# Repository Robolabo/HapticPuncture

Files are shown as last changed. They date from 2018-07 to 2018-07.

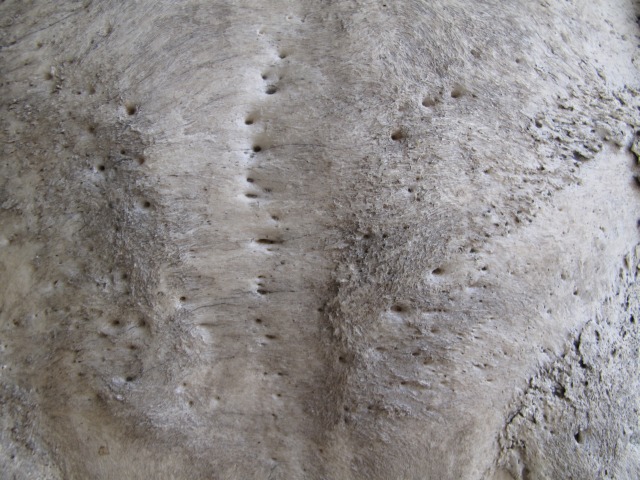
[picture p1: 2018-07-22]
resources/images/bone.jpg

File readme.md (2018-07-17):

HapticPuncture - The Open Source Haptic Puncture Simulator
----------------------------------------------------------

Introduction
============

HapticPuncture Simulator is an innovative simulation system for epidural anesthesia training. Among its many advantages it is important to say that it is virtual-reality (VR) based, which means that can be used indefinitely. Moreover, it is a low-cost, open-source, customizable prototype that opens doors to new procedure simulators in multiple specialties of medicine.

This guide allows to any user to install the simulator downloaded from \url{www.github.com/robolabo}, and to start using the proposed simulator in \textbf{Ubuntu 14.04}. Furthermore, instructions about how to create new applications are detailed. 

HapticPuncture Simulator is composed by two main modules: an haptic device and a virtual environment. In order to use this system, some requirements exist.

Online Resources
================

* The release is available online in GitHub. 

  https://github.com/Robolabo

* Instructions on how to get started can be found in the 
  documentation folder.

  doc/getting-started.pdf

Materials
=========

The materials used in for the HapticPuncture Simuator 
prototype are listed below. A more detailed list can 
be found in the documentation folder.

  doc/getting-started.pdf

* A computer with Ubuntu 14.04

* An Arduino Due board

* A motor's board X-NUCLEO-IHM04A1

* A voltage generator

* A DC motor MINIMOTOR 2842-012C

* An encoder HEDS 5540 A

* 3D printed structures

* Two Linear Shaft Rail Bars

* Two bearings

* A transmission tendon

* A capstan

* A pulley

Software Requirements
=====================

HapticPuncture requires the following software resources:

* CHAI3D platform.

* Arduino IDE, with two libraries installed: Encoder.h and DueTimer.h.

* The code provided in this folder.

Libraries needed for CHAI3D:
* GLUT package
$sudo apt-get install freeglut3 freeglut3-dev
$sudo apt-get install binutils-gold
* usb-1.0
$sudo apt-get install libusb-1.0-0-dev
* libasound2-dev
$sudo apt-get install libasound2-dev

* Additionally, we need a compiler (gcc):
$sudo apt-get install build-essentials
* pthread 
* rt 
* dl 
* GL 
* GLU 
* usb-1.0

Start the system
================

The C++ code to run the virtual environment needs to be compiled. Firstly, copy the 07-HapticPuncture directory from <HapticPunture directory>/Chai3D_code to <CHAI3d_directory>/GEL/modules/GEL/examples/GLFW/
Then, run in the command line:
$ cd <HapticPunture directory>/Chai3D_code/07-HapticPuncture
$ make

Next, to run HapticPuncture the following code scripts need to be run:
* `Arduino_code/HapticPuncture_arduino.ino` in arduino
* `Chai3D_code/07-HapticPuncture/obj/release/lin-x86_64-ccHapticPuncture/HapticPuncture` by typing in the terminal from lin-x86_64-ccHapticPuncture directory: $ ./HapticPuncture

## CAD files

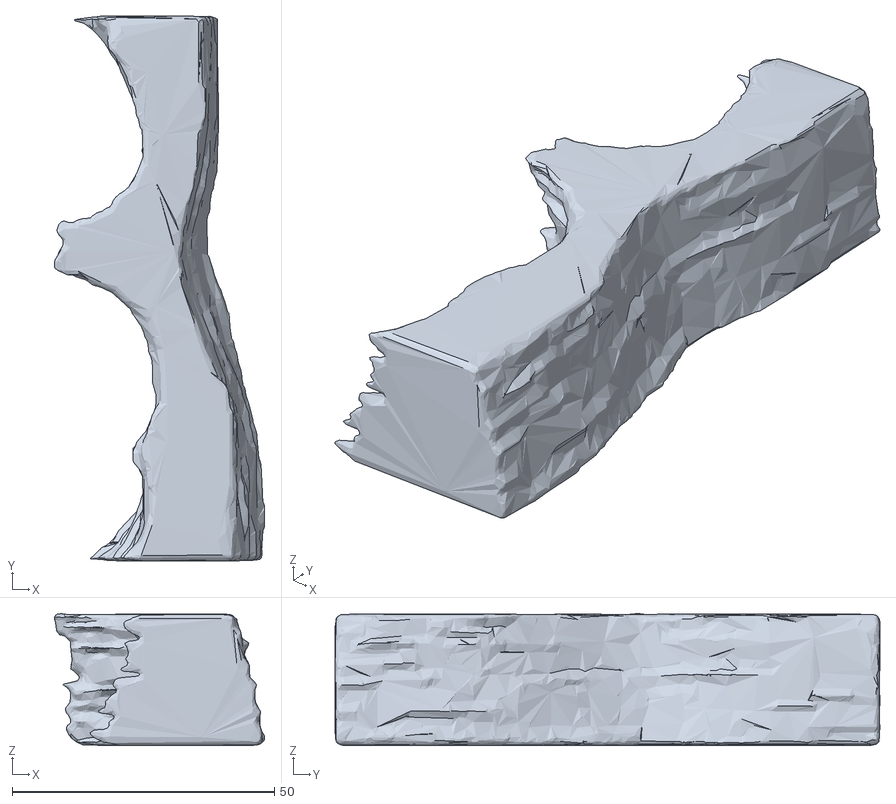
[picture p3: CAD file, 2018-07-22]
resources/models/conjunctive/conjunctive_filled_center.stl
40.1 x 104.0 x 25.2

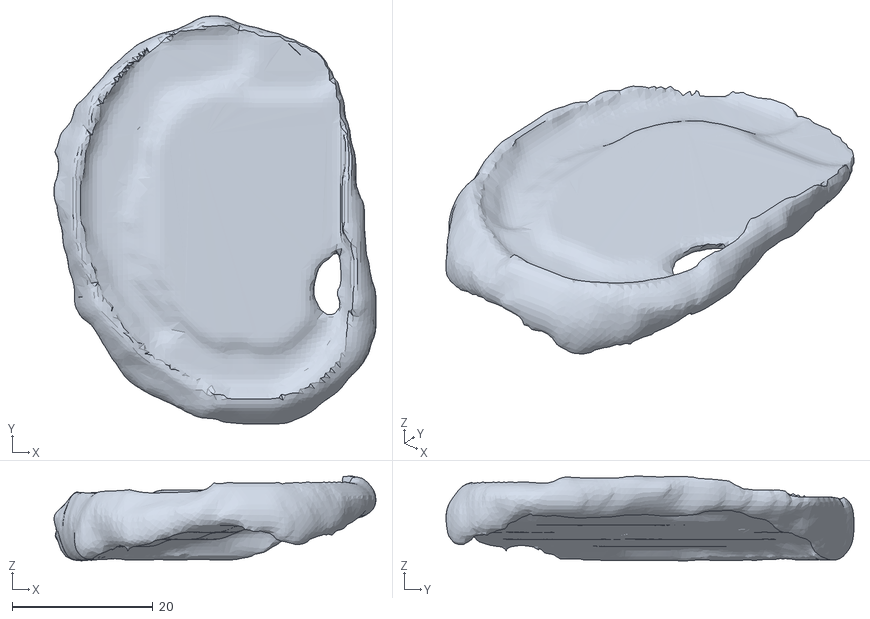
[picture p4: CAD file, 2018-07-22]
resources/models/disk/disk_filled_center.stl
45.7 x 57.9 x 12.0

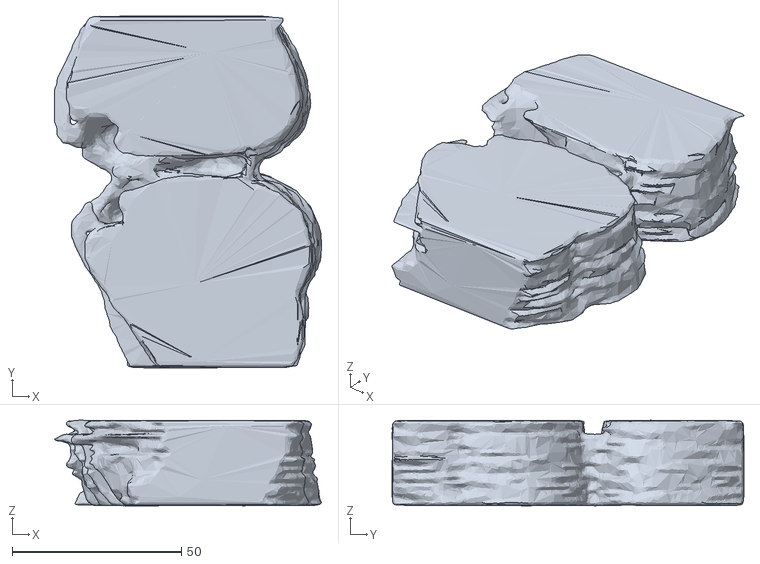
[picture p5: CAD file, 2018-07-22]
resources/models/muscle/muscle_filled_center.stl
79.0 x 104.0 x 25.4

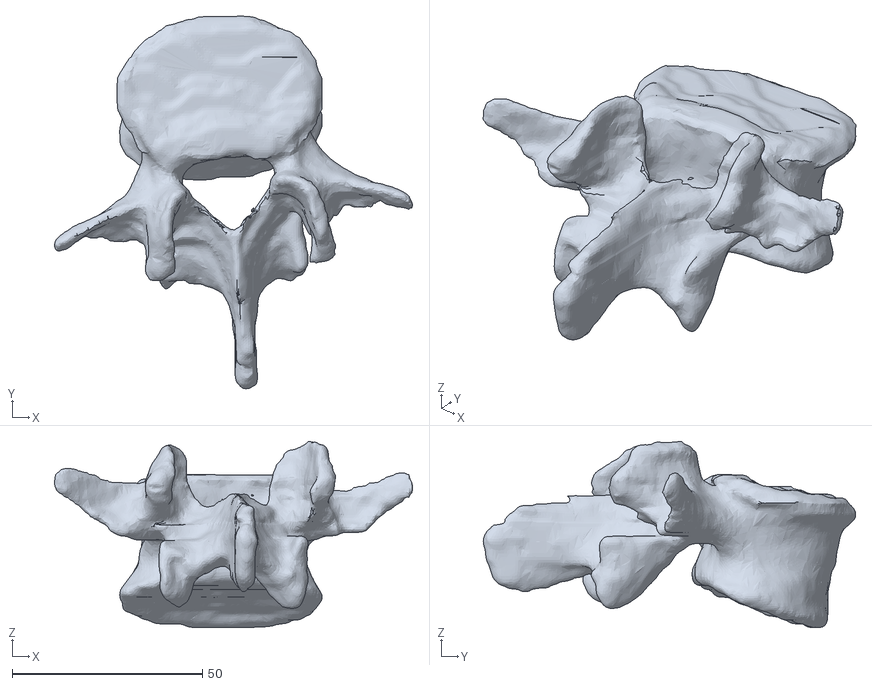
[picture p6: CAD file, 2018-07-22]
resources/models/vertebra1/vertebraD.stl
94.0 x 97.8 x 48.9

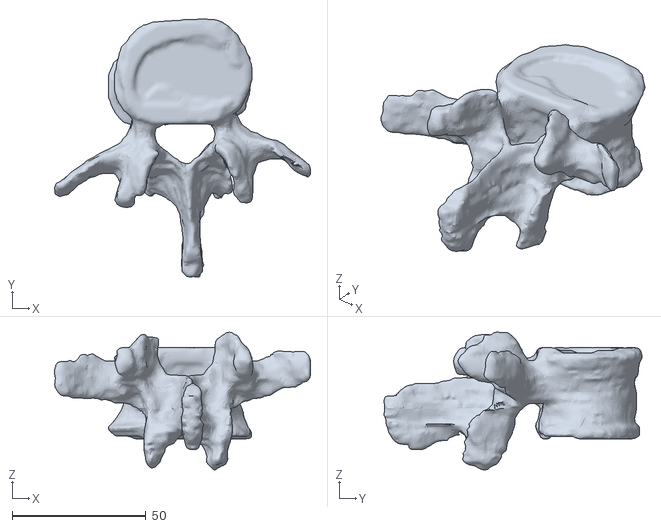
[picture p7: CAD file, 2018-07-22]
resources/models/vertebra2/vertebraU.stl
95.7 x 96.5 x 51.5

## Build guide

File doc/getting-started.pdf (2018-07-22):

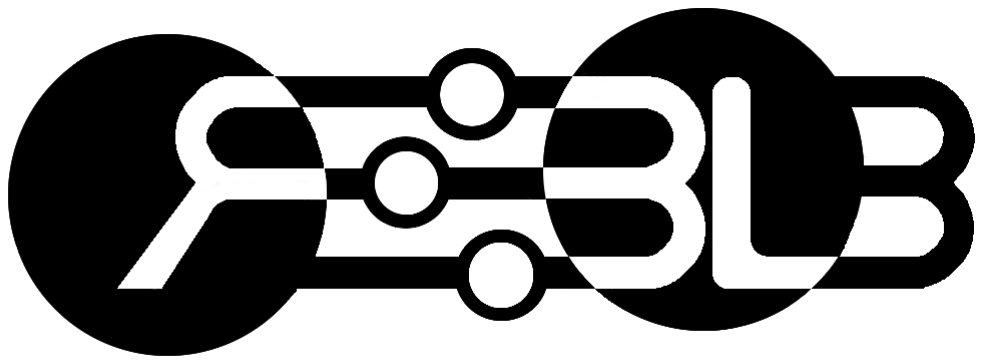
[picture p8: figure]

# HapticPuncture Simulator manual

## TM/ROBOLABO/2016

## Developed by ROBOLABO

www.robolabo.etsit.upm.es

Authors:
Juana Gonz´alez-Bueno
Dr. Alvaro Guti´errez Mart´ın

July 15, 2018

# Contents

### 4 CONTENTS

## 0.1 Introduction

HapticPuncture Simulator is an innovative simulation system for epidural anesthesia training. Among its many advantages it is important to say that it is virtual-reality (VR) based, which means that can be used indefinitely. Moreover, it is a low-cost, open-source, customizable prototype that opens doors to new procedure simulators in multiple specialties of medicine.

This guide allows to any user to install the simulator downloaded from www.github. com/robolabo, and to start using the proposed simulator in Ubuntu 14.04. Furthermore, instructions about how to create new applications are detailed.

HapticPuncture Simulator is composed by two main modules: an haptic device and a virtual environment. In order to use this system, some requirements exist.

## 0.2 Materials

- A computer with Ubuntu 14.04
- An Arduino Due board
- A motor’s board X-NUCLEO-IHM04A1 available online (http://www.st.com/content/st_com/en/products/ecosystems/stm32-open-development-environment/stm32-nucleo-expansion-boards/stm32-ode-move-actuate-hw/x-nucleo-ih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)
- A voltage generator
- A DC motor MINIMOTOR 2842-012C
- An encoder HEDS 5540 A
- 3D printed structures, that can be found in the /3D-structures folder.
- Two Linear Shaft Rail Bars available online (https://www.aliexpress.com/item/One-set-Prusa-i3-Single-Sheet-Frame-OD8mm-Smooth-Rods-Chrome-Precision-Hardened-Rod-Linear-Shaft/32235157842.html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)
- Two bearings available online (https://www.aliexpress.com/item/NEW-11-x-LM8UU-3-x-608ZZ-2-x-624ZZ-Bearing-Kit-for-RepRap-Wilson-TS/32241795995.html)
- A transmission wire
- A capstan
- A pulley

## 0.3 Installation

### 0.3.1 CHAI3D

First of all, HapticPuncture Simulator’s virtual module is based on CHAI3D. It is therefore necessary to install this software platform on your computer.

0.3. Installation | 5

To do that download the current CHAI3D software version from http://www.chai3d.org/download/releases. (http://www.chai3d.org/download/releases) Choose the file named ”chai3d-version-multiplatform.zip”. For this simulator version 3.1.1 was used.

Unzip in the desired work folder.

Open the terminal and go into the unziped folder. Execute:

$ make

For this to work it is necessary to have previously installed:

- GLUT package:

$sudo apt - get install freeglut3 freeglut3 - dev $sudo apt - get install binutils - gold

- libusb-1.0-0-dev

$sudo apt - get install libusb -1.0 -0 - dev

- libasound2-dev

$sudo apt - get install libasound2 - dev

- Moreover it is necessary to have a compiler installed. Build-essentials is enough:

$sudo apt - get install build - essentials

For more information, read the CHAI3D documentation in the /doc folder.

### 0.3.2 Arduino

As the haptic device uses an Arduino Due, it is necessary to install the Arduino IDE. To do that follow the next steps:

Download the desired version of Arduino for Linux from Arduino. (https://www.arduino.cc/en/Main/Software) The version used in this prototype is arduino-1.6.5-r5.

Unzip

Go to the folder using the terminal and execute:

$ cd arduino - version
$ ./ arduino

Some libraries are required to use the code given in this project. For the purpose of this simulator, Encoder.h and DueTimer.h are needed. To install them download the library zip, from Encoder library (https://www.pjrc.com/teensy/td_libs_Encoder.html) and DueTimer library (https://github.com/ivanseidel/DueTimer) respectively. Then, open the Arduino IDE (explained just before) and select:

Program → Include Library → Add .ZIP library

### 6 CONTENTS

and then select the zip forlder that contains the desired library. Close the program and execute again.

## 0.4 Start the system

The C++ code to run the virtual environment needs to be compiled. Firstly, copy the “07-HapticPuncture” directory from HapticPunture directory /Chai3D code

to
CHAI3D directory /GEL/modules/GEL/examples/.

Then, run in the command line:

$ cd < HapticPunture directory >/ Chai3D_code /07 - HapticPuncture $ make

Next, to run HapticPuncture the following code scripts need to be run:

- Arduino code/HapticPuncture arduino.ino in arduino
- Chai3D code/07-HapticPuncture/obj/release/lin-x86 64-ccHapticPuncture/HapticPuncture by typing in the terminal from lin-x86 64-ccHapticPuncture directory:

$ ./ HapticPuncture

## 0.5 Customize your models

To either use different tissue models or to modify the parameters to perceive different haptic feedbacks, you will need to modify the file “HapticPuncture.cpp” inside Chai3D code/07-HapticPuncture.

### 0.5.1 Using different models

First of all, you will need to add your new models inside the folder ressources/models/. Note each tissue has to be in a different file if you will want to assign different parameters to each of them. Note as well that the models have to be in “.stl” format, and shouldn’t contain a high number of vertices, as the haptic rate will decrease.

Secondly, inside “HapticPuncture.cpp” you will need to modify the path to each of your models. Inside the model section, modify the code to load the model.

### 0.5.2 Modify your model’s parameters

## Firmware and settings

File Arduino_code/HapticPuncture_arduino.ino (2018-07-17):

/*
 ****************************************************************************
 *                     HAPTIC PUNCTURE SIMULATOR
 ****************************************************************************
 * Haptic Punture is an open-source, virtual reality based simulator 
 * for training in epidural procedures. The haptic device is composed by a 3D 
 * structure, moved by a DC motor. The position is recorded by an encoder. 
 * 
 * This code allows to measure the position information of the haptic device.
 * Then it sends it to the virtual environment (CHAI3D based) via port commu-
 * nication. Finally, the forces generated by the models simulation are tran-
 * slated to the motor.
 */

/*------------------------------------------------
 * author:          	      Juana González-Bueno
 * Robolabo, ETSIT, Technical University of Madrid
 * -----------------------------------------------
 */

#include <Encoder.h>
#include <DueTimer.h>
#include <stdlib.h>  

// Motor pins definition
int CHA   = 6;        // Input of A channel from the encoder
int CHB   = 7;        // Input of B channel from the encoder
int IN1   = A0;       // IN1 ouput to the motor's H bridge
int IN2   = A1;       // IN2 ouput to the motor's H bridge
int EN    = A4;       // EN output to enable the motor

// Variables declaration
int32_t   positionM;  // motors position given by the encoder
int       force;      // force sent to the H bridge as a PWM value
double    p;          // sampling period in [s]
int       maxPos;     // max encoder's position for this haptic device

// Encoder to read the motor's postition. 
Encoder myEnc(CHB, CHA);


void setup() {
  //Change the PWM frequency to 40KHz ----------------------------------------------------------------------------------------------------------------------------
  pmc_enable_periph_clk (PWM_INTERFACE_ID) ;  // turn on clocking to PWM unit

  //IN1A
  PWMC_ConfigureChannel (PWM, 0, 1, 0, PWM_CMR_CPOL) ;  // PWM, channel 0, divide CLKB = 84MHz by 2¹, alignment, polarity
  PWMC_SetPeriod (PWM, 0, 1050) ;             		// period = 1050 pwm clocks (20kHz) because: 1/((1/42000000)*1050)=40Khz
  PWMC_SetDutyCycle (PWM, 0, 100*1050/100) ;  		// duty set to 0% (CANAL 0 --> IN1A), with a 100% PWM because of the polarity
  PWMC_EnableChannel (PWM, 0) ;               		// enable
  
  //IN2A
  PWMC_ConfigureChannel (PWM, 1, 1, 0, PWM_CMR_CPOL) ;  // PWM, channel 1, divide CLKB = 84MHz by 2¹, alignment, polarity
  PWMC_SetPeriod (PWM, 1, 1050) ;           		// period = 1050 pwm clocks (20kHz) because 1/((1/42000000)*1050)=40Khz
  PWMC_SetDutyCycle (PWM, 1, 0*1050/100) ;  		// duty set to 0% (CANAL 1 --> IN2A)
  PWMC_EnableChannel (PWM, 1);             		// enable
  
  //IN1B
  PWMC_ConfigureChannel (PWM, 3, 1, 0, PWM_CMR_CPOL) ; 	// PWM, channel 3, divide CLKB = 84MHz by 2¹, alignment, polarity
  PWMC_SetPeriod (PWM, 3, 1050) ;           		// period = 1050 pwm clocks (20kHz) because 1/((1/42000000)*1050)=40Khz
  PWMC_SetDutyCycle (PWM, 3, 0*1050/100) ;  		// duty set to 0% (CANAL 3 --> IN1B)
  PWMC_EnableChannel (PWM, 3) ;             		// enable

  //IN2B
  PWMC_ConfigureChannel (PWM, 6, 1, 0, PWM_CMR_CPOL) ;  // PWM, channel 6, divide CLKB = 84MHz by 2¹, alignment, polarity
  PWMC_SetPeriod (PWM, 6, 1050) ;           		// period = 1050 pwm clocks (20kHz) because 1/((1/42000000)*1050)=40Khz
  PWMC_SetDutyCycle (PWM, 6, 0*1050/100) ;  		// duty set to 0% (CANAL 6 --> IN2B)
  PWMC_EnableChannel (PWM, 6) ;             		// enable

  // Configure pin PC3 (pin35), PC9 (pin 41) y PC18 (pin45) to be driven by peripheral B (PWM channel 0 L)
  // enable pin PC3 (pin35), PC9 (pin 41) y PC18 (pin45)
  PIOC->PIO_PDR = 0x40208 ;    // disable PIO control. 0x40200 Para los 2 pines
  PIOC->PIO_IDR = 0x40208 ;    // disable PIO interrupts
  PIOC->PIO_ABSR |= 0x40208 ;  // switch to B peripheral

  // Configure pin PA19 (pin42), to be driven by peripheral B (PWM channel 0 L) (with retrofeed)
  // enable pin PA19 (pin42)
  PIOA->PIO_PDR = 0x80000;    // disable PIO control
  PIOA->PIO_IDR = 0x80000;    // disable PIO interrupts
  PIOA->PIO_ABSR |= 0x80000;  // switch to B peripheral
  //-----------------------------------------------------------------------------------------------------------------------------------------------------------------
  
  // BaudRate = 115200 bps
  Serial.begin(115200);
  
  // Initialize output pin to the H bridge and enable it (now at 0V)
  pinMode(EN,OUTPUT);
  digitalWrite(EN, HIGH);

  // Change the default analogRead() resolution from 10 bits to 12 bits
  analogReadResolution(12);
  
  // Variables' initialization
  positionM     = 0;      // initial motor's position to 0
  p             = 0.0001; // sampling rate as 1ms
  maxPos        = 9000;   // measured with the current haptic device

  // Start timer to send and receive data
  Timer3.attachInterrupt(mainFunction);
  Timer3.start(p*1000000); // from [s] to [us]
  
}


/*
 * Function to set the motor's voltage by sending a PWM to the H bridge
 */
void setForce(){
  // When the force is 0: stop the motor
  if (force = 0.0){
    digitalWrite (EN, HIGH);
    PWMC_SetDutyCycle (PWM, 6, 0*1050/100) ;      // duty set to 0% (CHANNEL 3 --> IN1) (same as digitalWrite(IN1, LOW);)
    PWMC_SetDutyCycle (PWM, 3, 0*1050/100) ;      // duty set to 0% (CHANNEL 6 --> IN2) (same as digitalWrite(IN2, LOW);)
  }

  // When the force is positive, enable the H bridge and define de motor's direction as FORWARD
  else if (force > 0.0) {
    if (force > 100.0) {
      force = 100.0;
    }
    digitalWrite (EN, HIGH);
    PWMC_SetDutyCycle (PWM, 6, 0*1050/100) ;      // duty set to 0% (CHANNEL 6 --> IN2) (same as digitalWrite(IN2, LOW);)
    PWMC_SetDutyCycle (PWM, 3, force*1050/100) ;  // duty set to pwm% (CHANNEL 3 --> IN1)
  }

  // When the force is negative, enable the H bridge and define de motor's direction as BACKWARDS
  else if (force < 0.0) {
    if (force < -100.0) {
      force = -100.0;
    }
    digitalWrite (EN, HIGH);
    PWMC_SetDutyCycle (PWM, 3, 0*1050/100) ;      // duty set to 0% (CHANNEL 3 --> IN1)
    PWMC_SetDutyCycle (PWM, 6, -force*1050/100) ; // duty set to pwm% (CHANNEL 6 --> IN2)
  }
}

/*
 * Function send the position and receive the force.
 * Calls the setForce() function
 */
void mainFunction() {
  // Read the motor's position from the encoder
  // converted to a value from 0 to 255
  positionM = abs(myEnc.read()*255/maxPos);

  // Limitation of the variable
  if (positionM > 255) {
    positionM = 255;
  }

  // Send the position value through the port (0 to 255)
  // Receive the force value through the port (PWM)
  if (Serial.available() > 0) {
    Serial.write(positionM);
    force = Serial.read();
    setForce();
  }
}


/*
 * Eternal loop to make the program work
 */
void loop() {
  while(1){
  }
}
